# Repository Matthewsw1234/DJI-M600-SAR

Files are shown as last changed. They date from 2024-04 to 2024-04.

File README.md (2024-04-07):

# DJI-M600-SAR

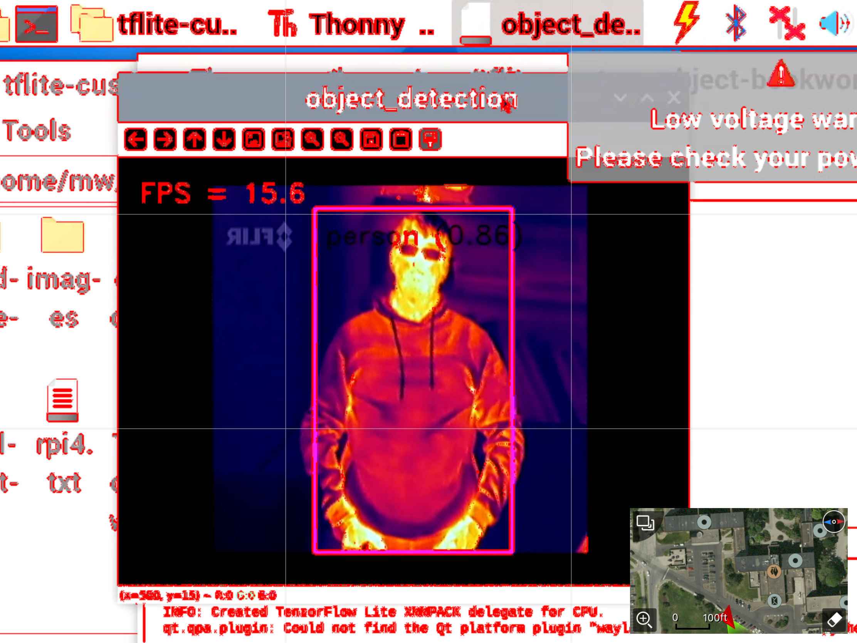
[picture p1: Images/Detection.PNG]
Image of Working Detection

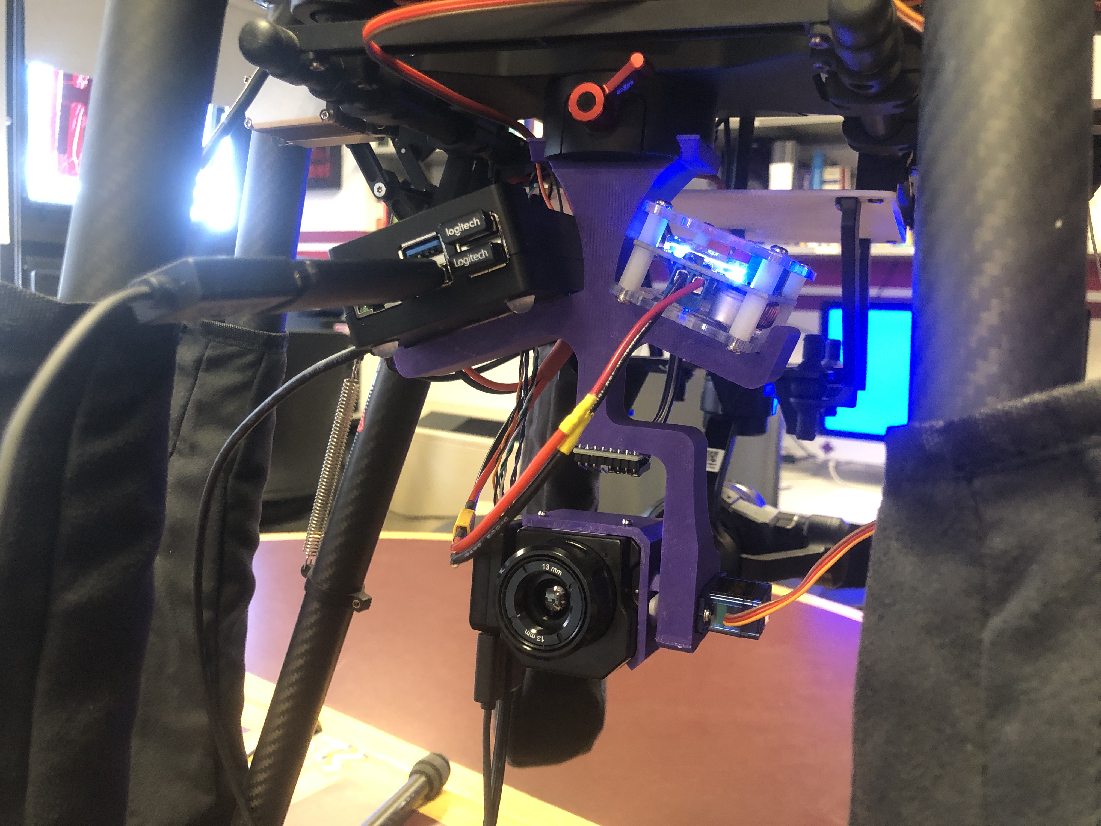
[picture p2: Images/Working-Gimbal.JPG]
Image of Gimbal On Drone


M600 Drone Custom Thermal Detection Payload With Gimbal Using Tensorflow Lite

This Project is currently not in its full state. It currently is a proof of concept that I wish to take further with updates over time.

## How to set up on Raspberry Pi for object detection (Note: Only tested on Pi 5 with Bookworm OS as of 4/1/2024)

Installation on a Fresh Install of Bookworm, please set up an internet connection beforehand

Type these commands into Command Terminal

Set up a VM if you want, I did not as this is the only purpose this Pi will be used for currently

``` shell
sudo apt-get update

sudo apt-get upgrade

sudo rm /usr/lib/python3.11/EXTERNALLY-MANAGED (stops externally managed error)

sudo pip3 install opencv-python

sudo pip3 install mediapipe
```

That is it for setup.

## Setting up the Hardware/Software for FLIR, RPI, and Gimbal

Please look at 3 Files:

FLIR SETUP with Assistant 2 and FLIR UAS

Mounting the RPI, FLIR, and Buck Converter (WIP)

Final Connections and DJI Go setup (WIP)

## Launching the Programs

Once you have gone through the above setups. Open the repository on your Pi.

Open `FLIR-Detection.py` in Thonny or your Python runner of choice.

Run the program with the Flir Connected to the Pi. This will start the detection. For testing a USB webcam may work, but the model is not tuned for that.

Open `Gimbal.py` to start the Servo's balancing in Thonny or your Python runner of choice.

Make sure the MPU6050 is connected and the Servo before running. Yous should see the Gimbal lock to a certain pitch.

## Training your own model set

If you wish to do this, please take a look at the TRAIN YOUR OWN MODELS file if you want to capture/performance tune your own model set.

---

Note: The training method I use is using Google's Colab as I didn't want to set it up on my own machine.

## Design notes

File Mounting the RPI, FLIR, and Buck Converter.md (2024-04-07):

# Mounting The Raspberry Pi, FLIR, and Buck Converter to The Gimbal

## Making The Gimbal

Please first print the two STL files named: `FLIR GIMBAL HOUSING` and `FLIR GIMBAL ARM`.

Once Printed, grab the `FLIR GIMBAL HOUSING` and place a two way servo arm through the holes like this:

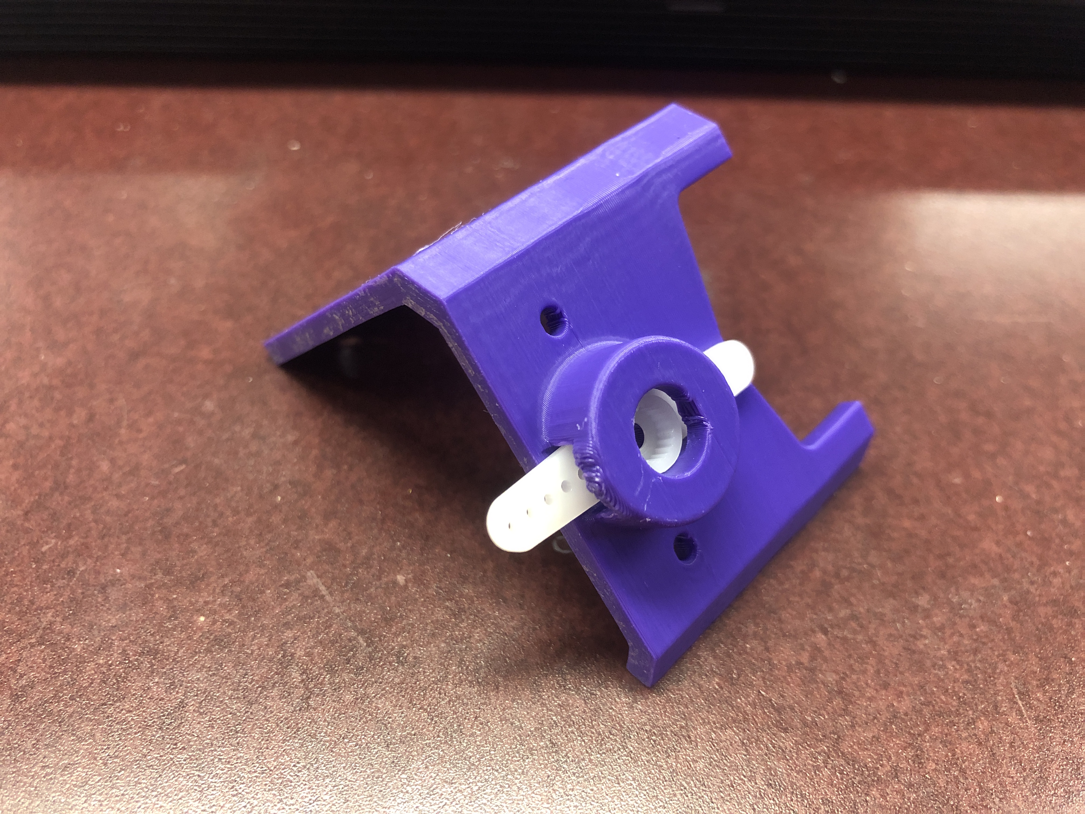
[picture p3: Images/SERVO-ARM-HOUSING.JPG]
Image of Servo Arm in Housing


Once Placed, grab your servo and place it into the `FLIR GIMBAL ARM` as shown:

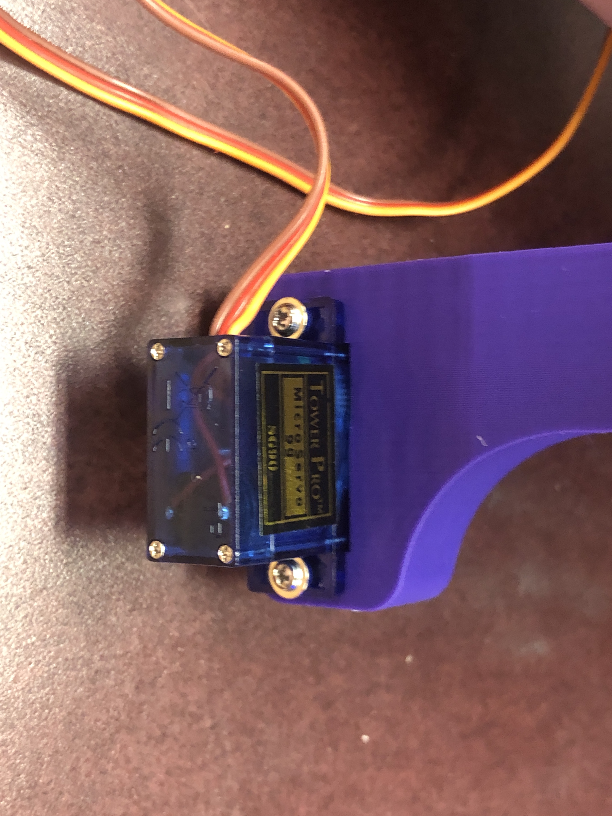
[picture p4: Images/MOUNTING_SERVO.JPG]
Image of Servo Mounting


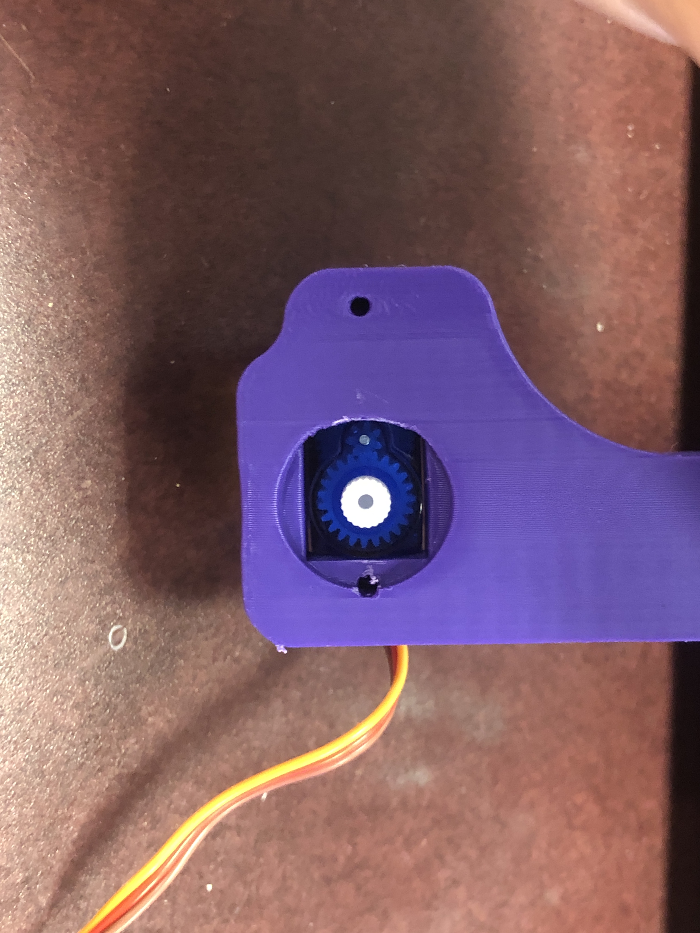
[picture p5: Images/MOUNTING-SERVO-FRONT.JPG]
Image of Servo Mounting


Once Placed, Grab a MPU6050 and mount it to the arm as shown:

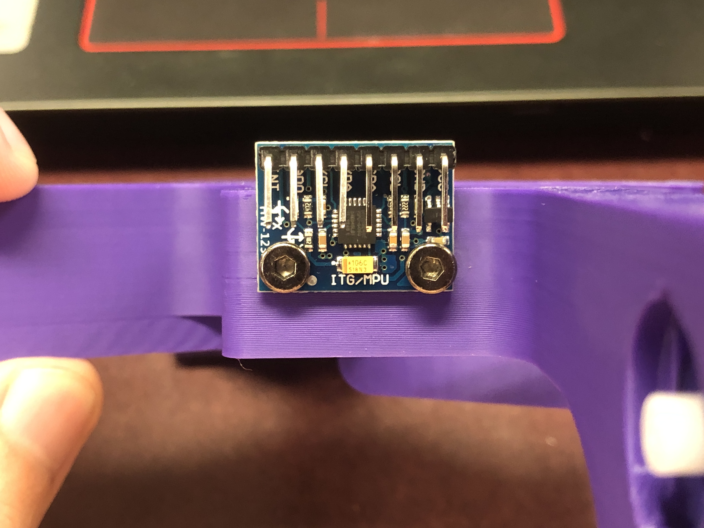
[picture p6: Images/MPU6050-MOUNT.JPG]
Image of mounting MPU6050 to ARM


Next, line up the housings hole on the inside and mount it to the servo/arm making sure to use the provided small screw that comes provided with the `SG90 Servo`.

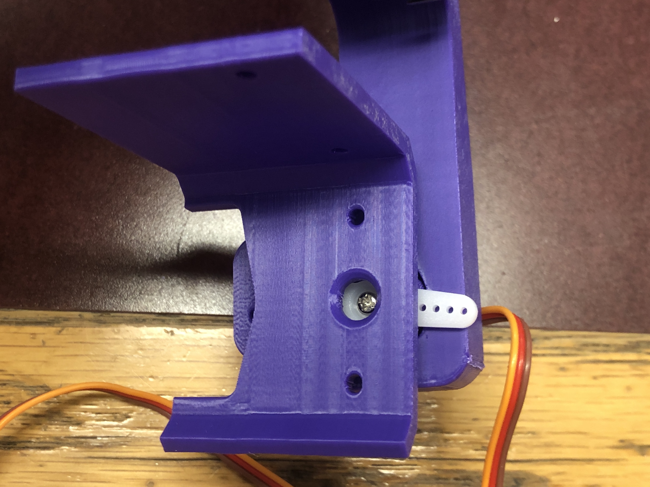
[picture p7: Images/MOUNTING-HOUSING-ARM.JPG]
Image of mounting Housing to ARM


Next, mount the `FLIR CAMERA` to the `FLIR GIMBAL HOUSING`.

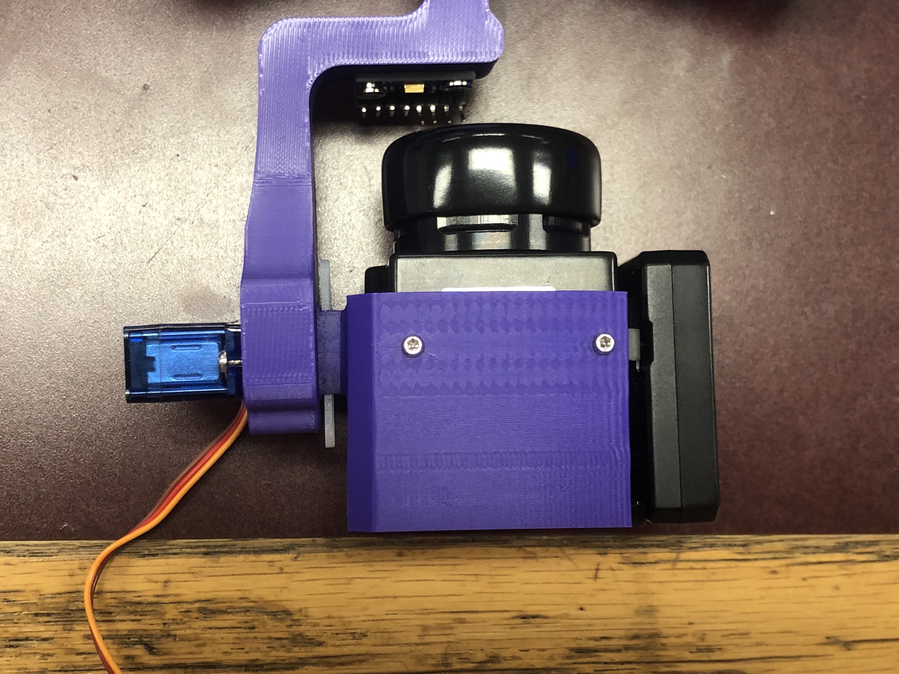
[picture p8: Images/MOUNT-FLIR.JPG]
Image of mounting FLIR to Housing


## Mounting Components To Gimbal Arm

Use Two Sided Tape/Adhesive to Mount the RPI and Voltage Buck Converter to the `GIMBAL ARM`.

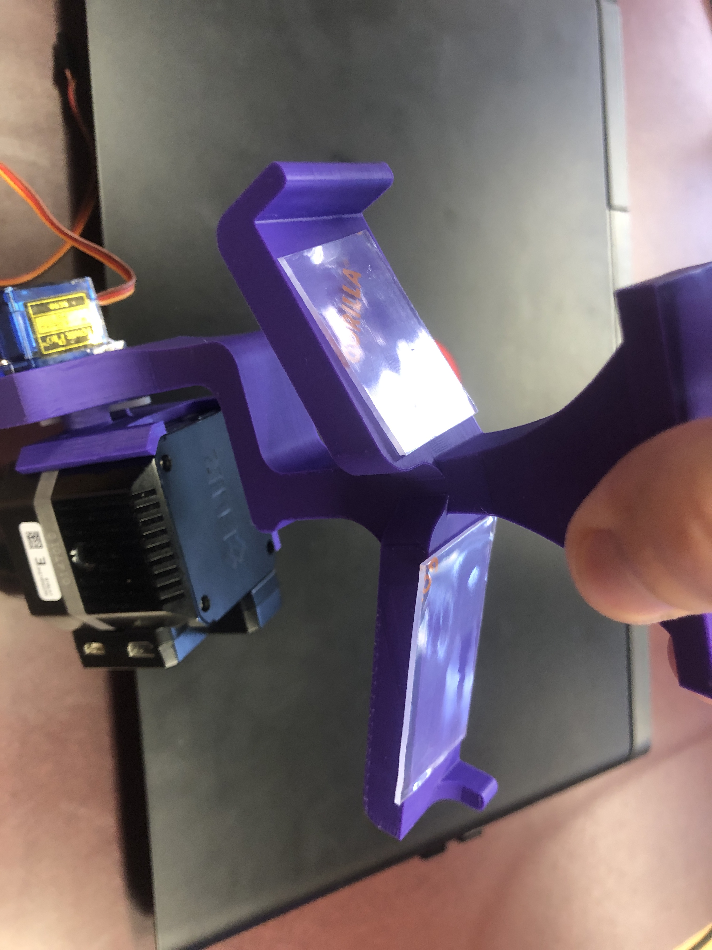
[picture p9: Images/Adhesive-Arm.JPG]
Image of the adhesive on the arm


Place Raspberry Pi on the longer side with the HDMI and Power facing Outwards.

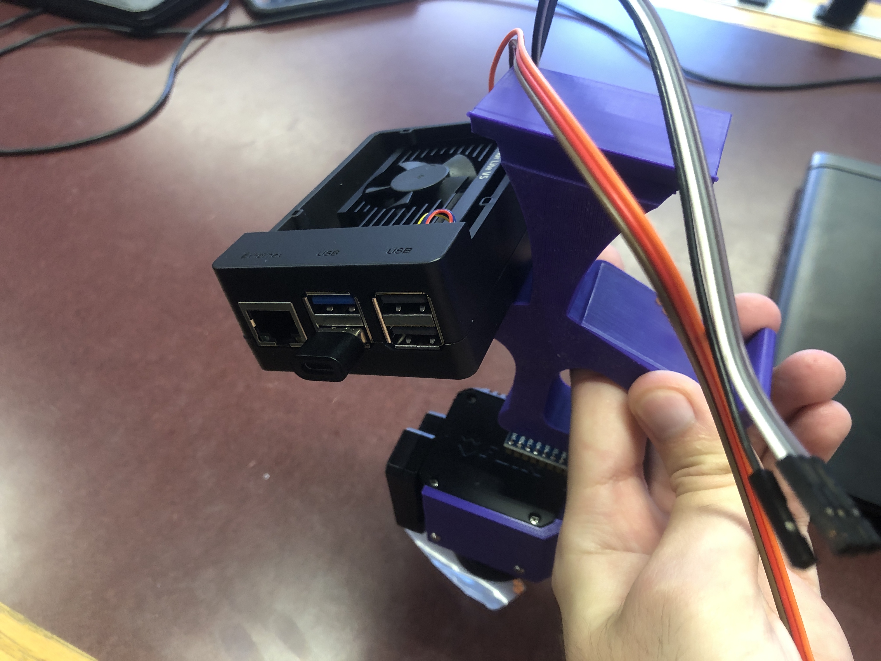
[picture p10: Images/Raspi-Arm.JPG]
Image of Raspberry Pi on Arm


Place the Voltage Buck Converter on the shorter side with the display facing out.

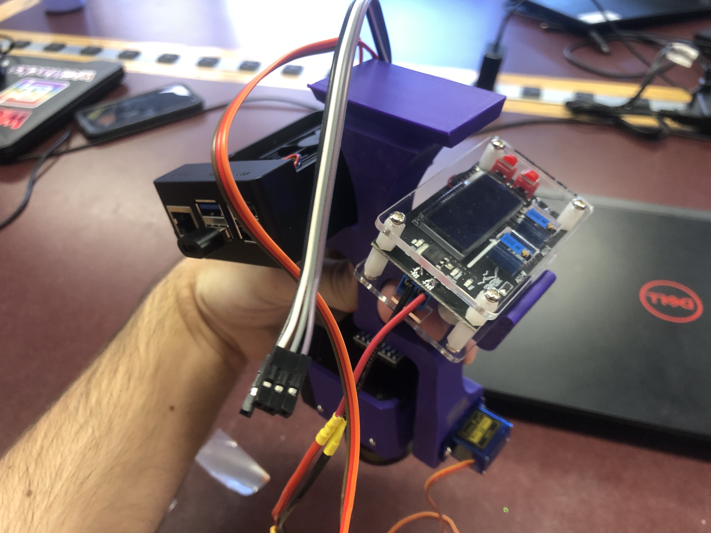
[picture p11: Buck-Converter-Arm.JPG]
Image of Buck Converter on Arm


Place Gimbal onto Ronin MX Mount. Can face towards the front or the rear.

Image of Gimbal on Drone

That is it for mounting. Please look at `Final Connections and DJI Go setup` for wiring the components together.

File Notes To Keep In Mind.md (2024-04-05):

# Notes to Keep in Mind

The Raspberry Pi 5 reccomends a power source of 5V 5A. I do not currently have this available so the FLIR is powered by a mobile battery pack until solved.

The Output/Input of the RPI through Lightbridge 2 is not perfect. I am working on a fix but for now I reccomend running the scripts before launch.

When Printing the parts, Make sure the FLIR GIMBAL and FLIR GIMBAL ARM have not warped when printing. This can cause issues with balancing and RPI/Buck Converter security.

Look out for interference of the parts and wires when and after install. You don't want to have the cables disconnect when in the air or issues with the Power Cables.

The current servo connecting to the FLIR GIMBAL part has some play. That will be fixed in an updated model.

Please keep in mind this is not a professional or perfect setup. I have created this project out of Fun and Interest.

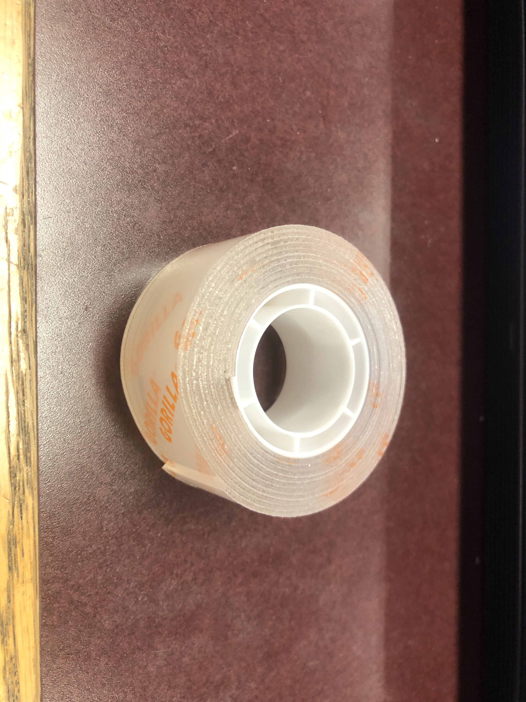
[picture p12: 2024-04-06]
Images/Two-sided-tape.JPG

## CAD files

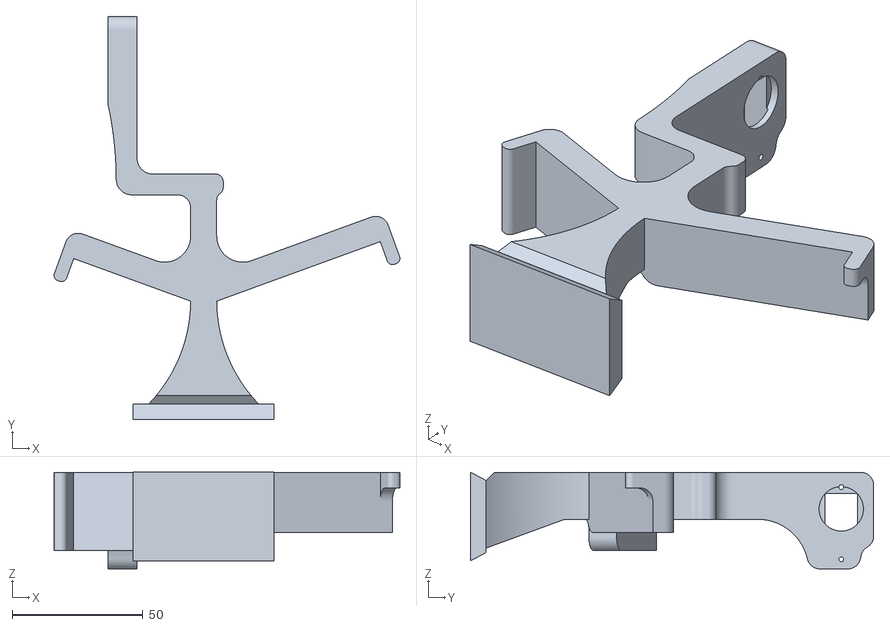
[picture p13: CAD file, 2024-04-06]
STL Files/FLIR GIMBAL ARM.stl
132.5 x 154.5 x 37.1

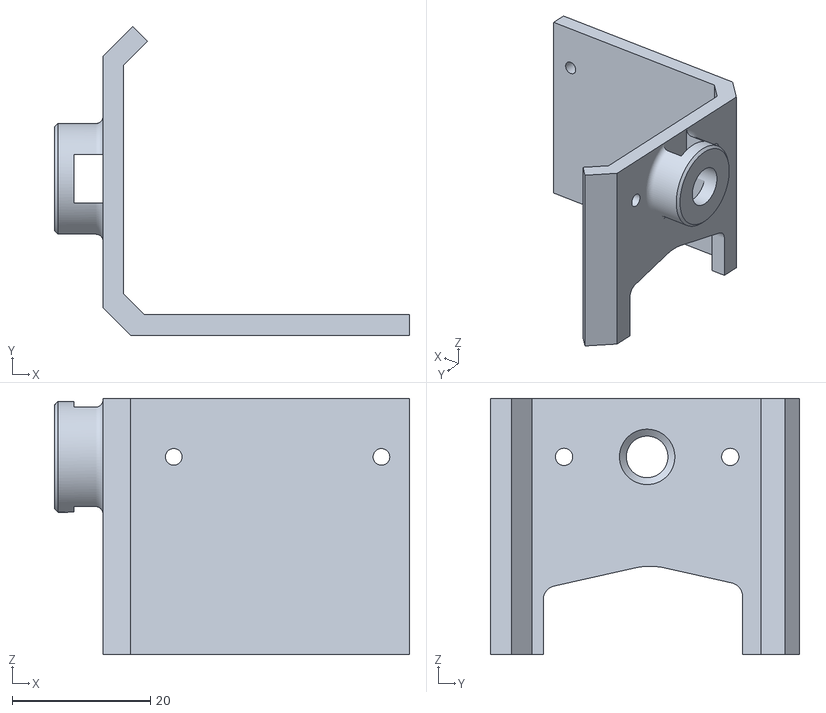
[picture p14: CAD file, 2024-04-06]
STL Files/FLIR GIMBAL HOUSING.stl
51.3 x 44.6 x 37.0

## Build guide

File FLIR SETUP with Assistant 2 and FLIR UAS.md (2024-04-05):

# Setup FLIR With DJI A3 And Lightbridge 2

This is to control the FLIR VUE PRO Through the DJI A3 and Lightbridge 2. Will Also work with DJI N3

This Uses the DJI Lightbridge 2 Channel Expansion Module. You can probably get this to work with the shutter button as well for taking Photos/Video, but the expansion module allows you to control more.

## FLIR Setup For PWM Control

Follow These Steps:

1. Download and open FLIR UAS App.
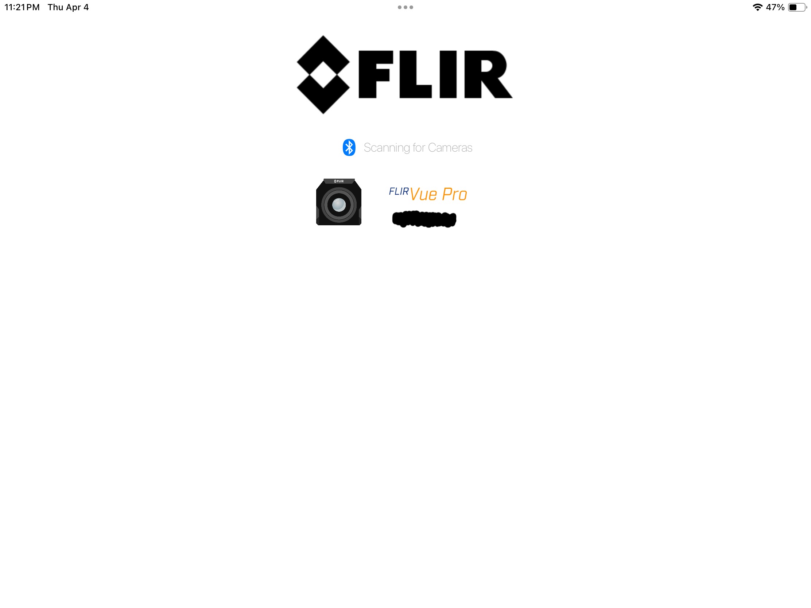
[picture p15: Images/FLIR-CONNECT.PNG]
Image of Flir Connection Page

1. Connect to FLIR VUE PRO.
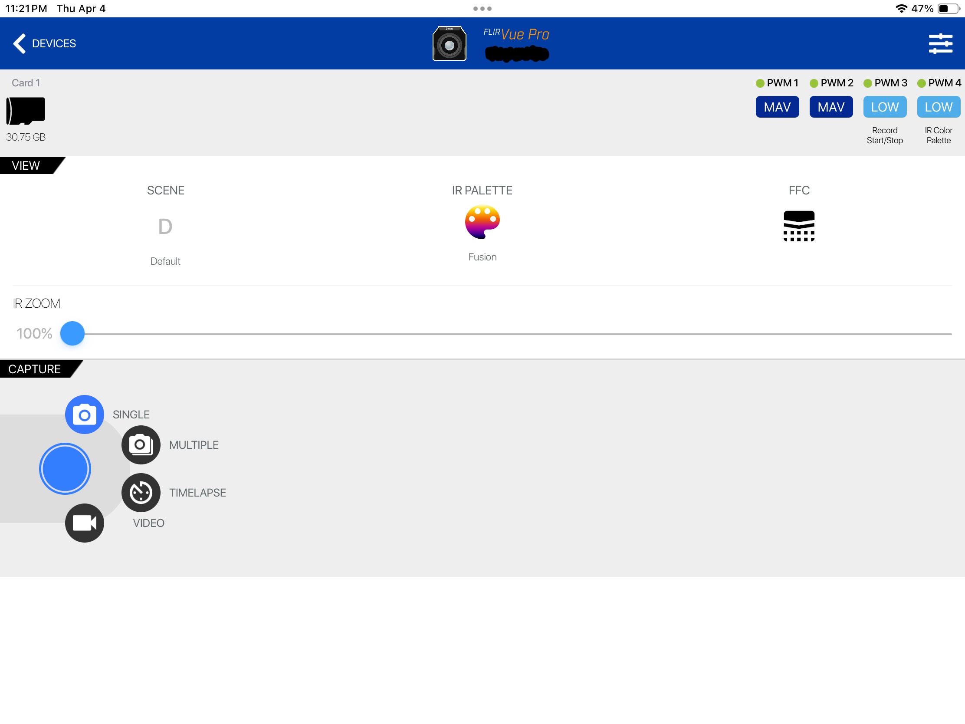
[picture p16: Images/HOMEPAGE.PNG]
Image of Flir Homepage

1. Navigate to the `Settings` page.
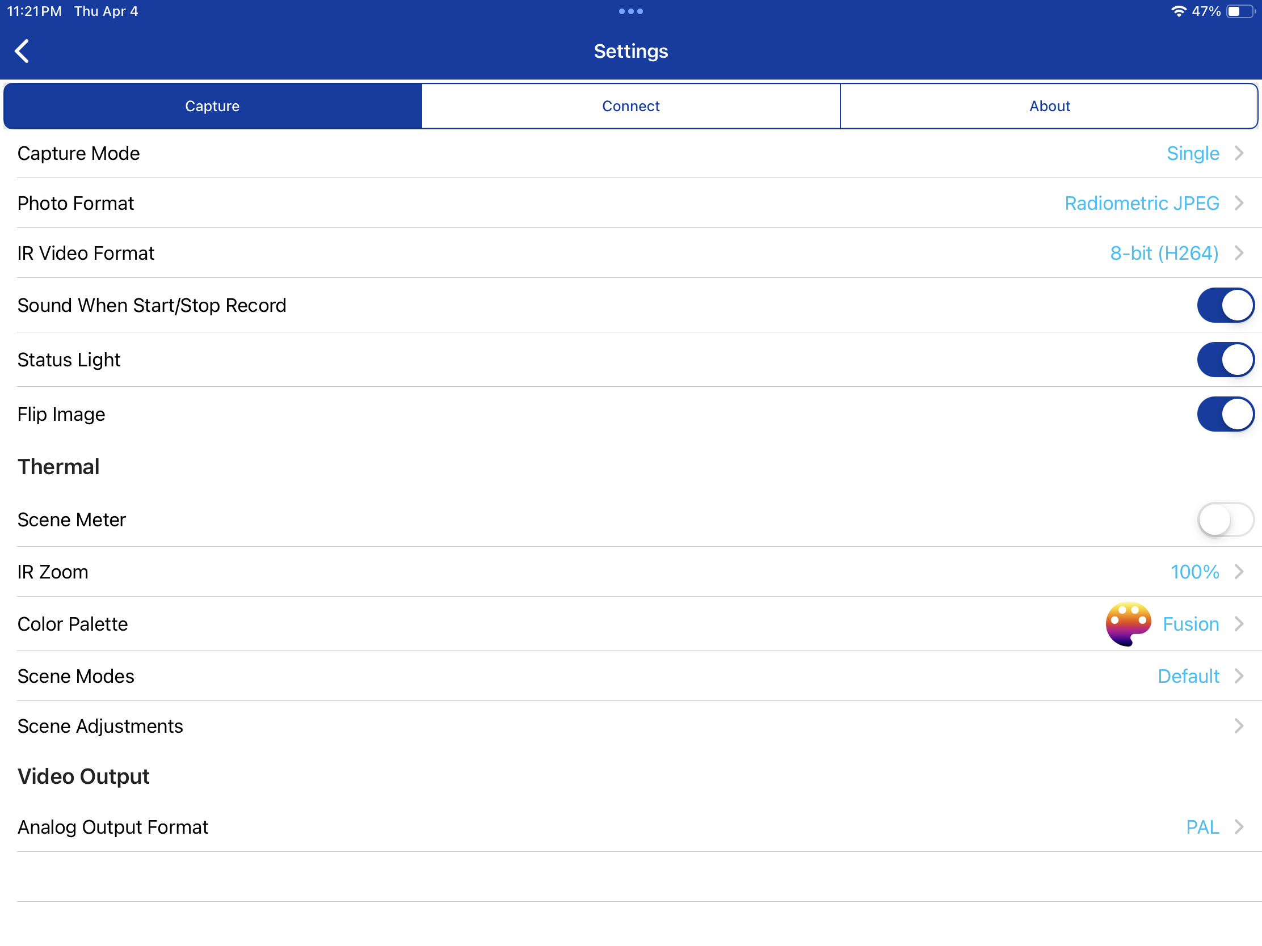
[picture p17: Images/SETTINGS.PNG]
Image of Settings Page

2. Go To `Connect`.
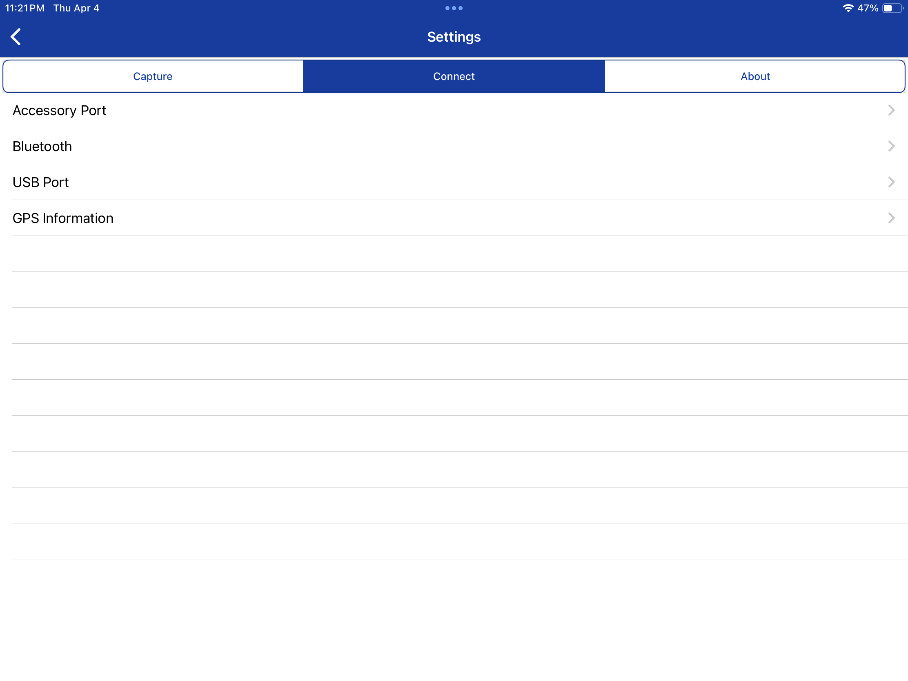
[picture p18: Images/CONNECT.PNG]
Image of Connect Page

3. Go To `Accessory Port`.
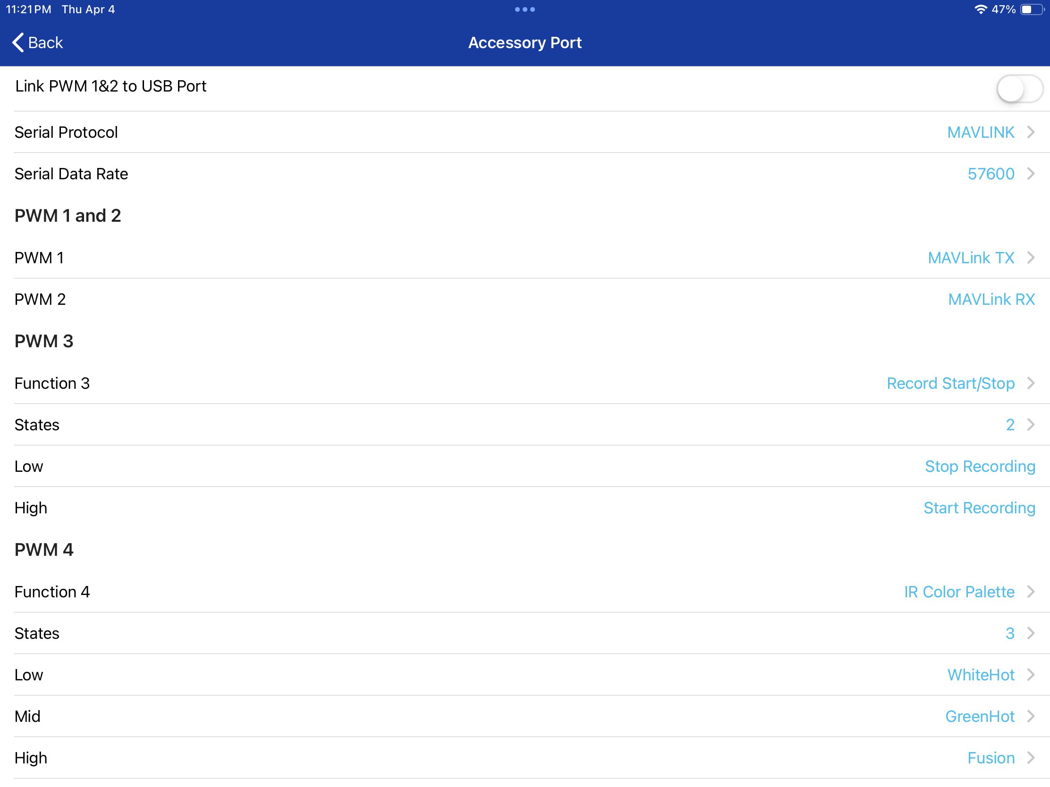
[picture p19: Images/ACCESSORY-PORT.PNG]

4. Set your `Function 3` and `Function 4`.
5. Choose if it is a 3 State or a 2 State.
6. Mine is configured as F3 `Record Start/Stop` 2 State with Low as Stop and High as Start Recording.
7.  F4 is configured as `IR Color Pallette` with 3 States. I have `White Hot, Green Hot, and Fusion` selected. Chooes your prefered State range.

Note: I have `Fusion` and `White Hot` in my trained model.

`Scene` is set as `Default`, though I use `SAR` as well. feel free to expirment with what you like.
Image of Flir Homepage

## Connection To A3/N3

Download `DJI Assistant 2 For Enterprise` or `DJI Assistant 2 For Matrice`. I recommend Assistant 2 For Matrice if you have connection issues to the M600. I use version 2.0.13.

Connect a Micro USB port to the USB Hub on the Matrice 600. And turn the Copter on.

Open Assistant 2. You should see both the M600 and Lightbridge 2.
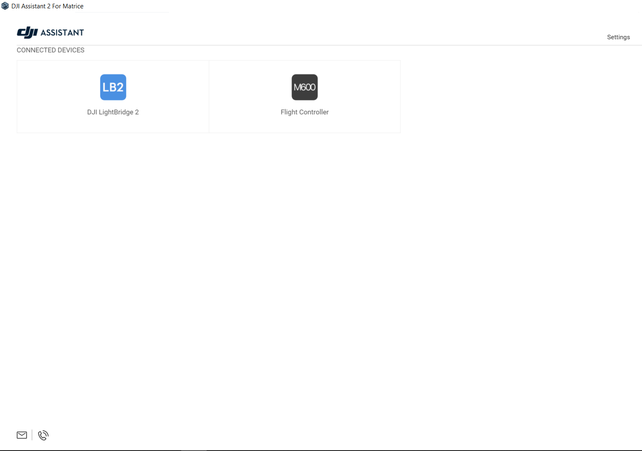
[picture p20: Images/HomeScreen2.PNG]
Image of Home Screen


Click on `M600`

Navigate to `Tools`
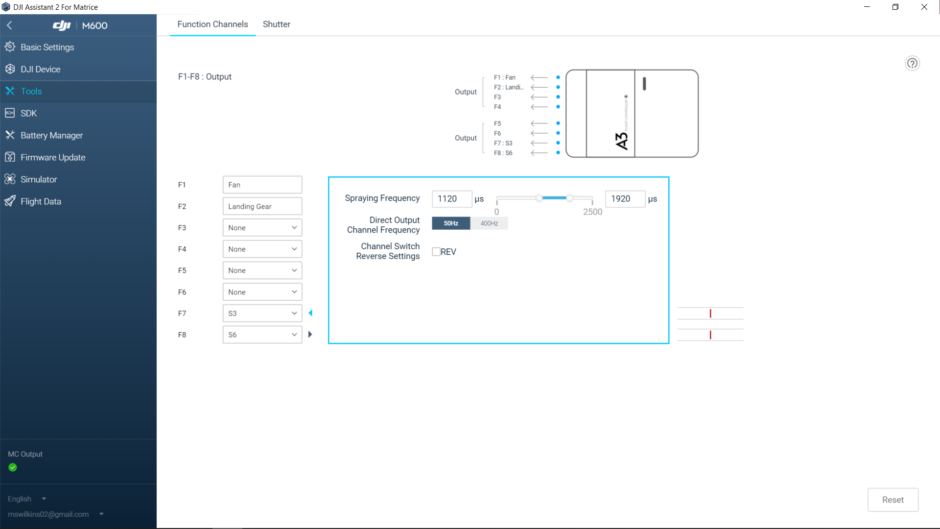
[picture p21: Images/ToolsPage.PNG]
Image of Tools Page


Config What F-PORT you want to use. I used F7 and F8 as those both have 3 Way switches. Feel free to choose yours based on what Funtions you chose in the FLIR App. I Just used Default settings in Assistant 2 Output.

Grab The FLIR VUE PRO Accessory Cable. There are 3 outputs. We are using the `Blue/Black` and `Orange/Black` cables.

Plug these cables into the F-PORTS Chosen on Assistant 2. `Orange/Black` is `PWM 3`, `Blue/Black` is `PWM 4`
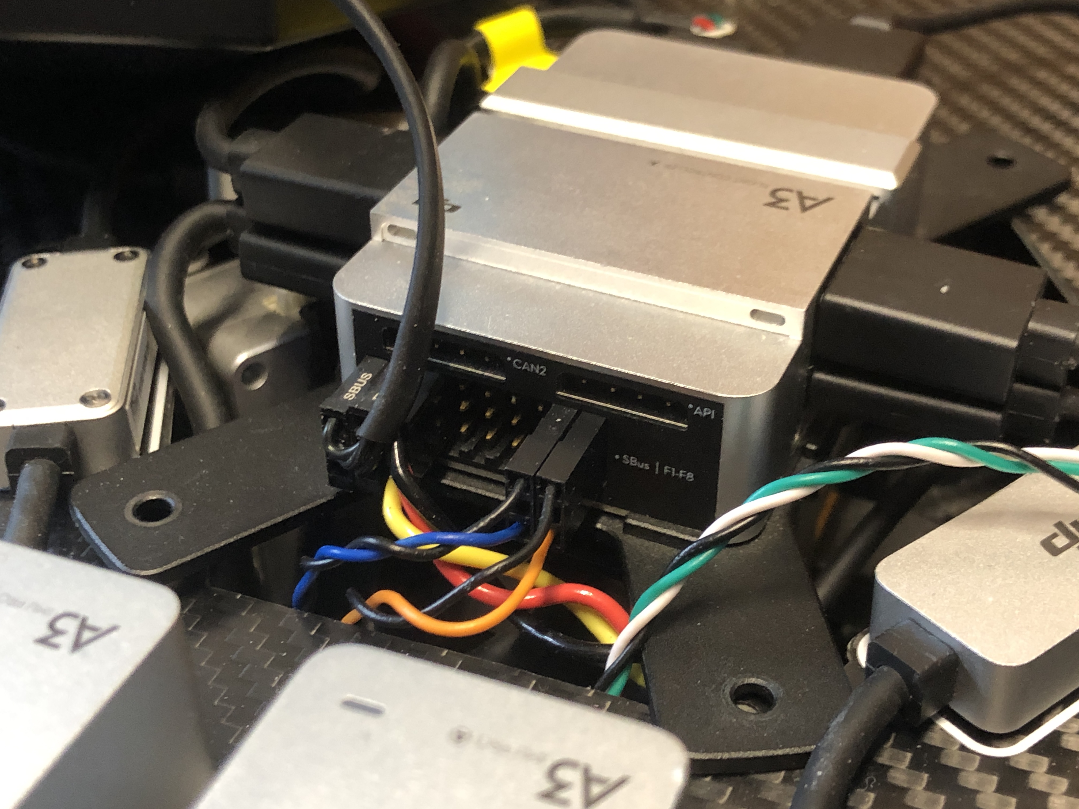
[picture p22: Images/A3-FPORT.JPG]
Image of the A3's F-Ports


Once These Cables are All Connected to the A3 and FLIR VUE PRO, Flip the switches or turn the knobs that correspond to the ports you chose. Look at Assistant 2 and the FLIR app to confirm the correct ports are connected.

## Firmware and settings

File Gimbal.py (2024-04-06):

from gpiozero import Servo
from time import sleep
from mpu6050 import mpu6050


servo_GPIO = 17

maxPW = 26/10000
minPW = 8/10000

servo = Servo(servo_GPIO,min_pulse_width=minPW,max_pulse_width=maxPW)

sensor = mpu6050(0x68)

servo_position = 0.0
prev_position = 0.0
step_val = 0.05

while True:
    accelerometer_data = sensor.get_accel_data()
    X = accelerometer_data ['x']
    print(X)
    
    #servo_position -= X/150
    servo_position = round(X/9.75, 2)
    
    if servo_position > 1:
        servo_position = 1
    elif servo_position < -1:
        servo_position = -1
    
    servo_position = round(servo_position, 2)
    print(servo_position)
    
    if((abs(servo_position) - abs(prev_position)) >= step_val):
        servo.value = servo_position
        
    sleep(0.1)

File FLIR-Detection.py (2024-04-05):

import argparse
import sys
import time

import cv2
import mediapipe as mp

from mediapipe.tasks import python
from mediapipe.tasks.python import vision

from utils import visualize

COUNTER, FPS = 0, 0
START_TIME = time.time()


def run(model: str, max_results: int, score_threshold: float, 
        camera_id: int, width: int, height: int) -> None:
  """Continuously run inference on images acquired from the camera.

  Args:
    model: Name of the TFLite object detection model.
    max_results: Max number of detection results.
    score_threshold: The score threshold of detection results.
    camera_id: The camera id to be passed to OpenCV.
    width: The width of the frame captured from the camera.
    height: The height of the frame captured from the camera.
  """

  # Uses FLIR CAMERA to capture
  cap = cv2.VideoCapture(0)
  cap.set(cv2.CAP_PROP_FRAME_WIDTH, width)
  cap.set(cv2.CAP_PROP_FRAME_HEIGHT, height)

  # Visualization parameters
  row_size = 50  # pixels
  left_margin = 24  # pixels
  text_color = (255, 255, 255)  # I use white is it makes it more visable on the Lightbridge 2 Display
  font_size = 1
  font_thickness = 1
  fps_avg_frame_count = 10

  detection_frame = None
  detection_result_list = []

  def save_result(result: vision.ObjectDetectorResult, unused_output_image: mp.Image, timestamp_ms: int):
      global FPS, COUNTER, START_TIME

      # Calculate the FPS
      if COUNTER % fps_avg_frame_count == 0:
          FPS = fps_avg_frame_count / (time.time() - START_TIME)
          START_TIME = time.time()

      detection_result_list.append(result)
      COUNTER += 1

  # Starts the Model
  base_options = python.BaseOptions(model_asset_path=model)
  options = vision.ObjectDetectorOptions(base_options=base_options,
                                         running_mode=vision.RunningMode.LIVE_STREAM,
                                         max_results=max_results, score_threshold=score_threshold,
                                         result_callback=save_result)
  detector = vision.ObjectDetector.create_from_options(options)


  # Constantly captures images from the FLIR and runs interference
  while cap.isOpened():
    success, image = cap.read()
    image=cv2.resize(image,(640,480)) # Resizes the Image
    if not success:
      sys.exit(
          'ERROR: Unable to read from webcam. Please verify your webcam settings.' # Error caused by Failure To Connect To Camera
      )

    image = cv2.flip(image, 1)

    # Convert the image from BGR to RGB as required by the TFLite model.
    rgb_image = cv2.cvtColor(image, cv2.COLOR_BGR2RGB)
    mp_image = mp.Image(image_format=mp.ImageFormat.SRGB, data=rgb_image)

    # Run object detection using the model.
    detector.detect_async(mp_image, time.time_ns() // 1_000_000)

    # Show the FPS
    fps_text = 'FPS = {:.1f}'.format(FPS)
    text_location = (left_margin, row_size)
    current_frame = image
    cv2.putText(current_frame, fps_text, text_location, cv2.FONT_HERSHEY_DUPLEX,
                font_size, text_color, font_thickness, cv2.LINE_AA)

    if detection_result_list:
        # print(detection_result_list)
        current_frame = visualize(current_frame, detection_result_list[0])
        detection_frame = current_frame
        detection_result_list.clear()

    if detection_frame is not None:
        cv2.imshow('object_detection', detection_frame)

    # Stops Detection If You Press ESC.
    if cv2.waitKey(1) == 27:
      break

  detector.close()
  cap.release()
  cv2.destroyAllWindows()


def main():
  parser = argparse.ArgumentParser(
      formatter_class=argparse.ArgumentDefaultsHelpFormatter)
  parser.add_argument(
      '--model',
      help='Path of the object detection model.',
      required=False,
      default='FLIR.tflite')
   #   default='YOUR-Model.tflite')
  parser.add_argument(
      '--maxResults',
      help='Max number of detection results.',
      required=False,
      default=5)
  parser.add_argument(
      '--scoreThreshold',
      help='The score threshold of detection results.',
      required=False,
      type=float,
      default=0.25)
  parser.add_argument(
      '--cameraId', help='Id of camera.', required=False, type=int, default=0)
  parser.add_argument(
      '--frameWidth',
      help='Width of frame to capture from camera.',
      required=False,
      type=int,
      default=640)
  parser.add_argument(
      '--frameHeight',
      help='Height of frame to capture from camera.',
      required=False,
      type=int,
      default=480)
  args = parser.parse_args()

  run(args.model, int(args.maxResults),
      args.scoreThreshold, int(args.cameraId), args.frameWidth, args.frameHeight)


if __name__ == '__main__':
  main()
